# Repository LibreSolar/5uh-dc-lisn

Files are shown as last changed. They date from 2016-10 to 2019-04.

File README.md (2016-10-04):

# 5uH-DC-LISN
5uH DC LISN (-10 dB attenuation)

This LISN enables you to perform basic EMC testing with your DC devices, e.g. power supplies.

The layout (especially the attenuation) is based on Linear Technology DC2130A board design and a [thread in the EEVblog forum](http://www.eevblog.com/forum/projects/5uh-lisn-for-spectrum-analyzer-emcemi-work/msg404662/#msg404662).

Further information on EMC testing can be found in [Würth Application Note ANP005](http://www.we-online.de/web/en/electronic_components/produkte_pb/application_notes/emv_filter_fuer_dc_dc_schaltregler_optimiert.php).

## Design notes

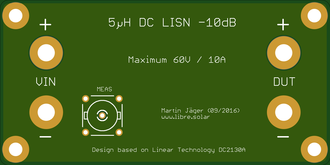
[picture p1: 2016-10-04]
5uH_LISN_bottom.png

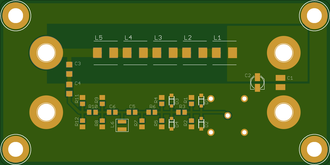
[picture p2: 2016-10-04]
5uH_LISN_top.png

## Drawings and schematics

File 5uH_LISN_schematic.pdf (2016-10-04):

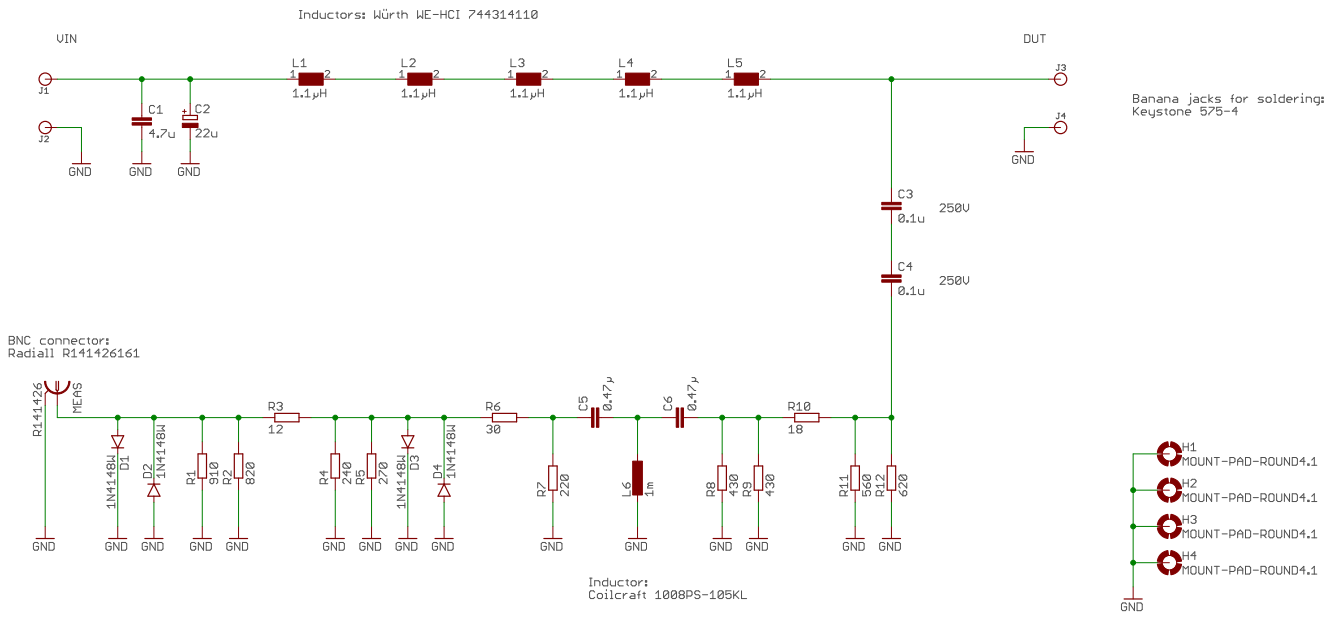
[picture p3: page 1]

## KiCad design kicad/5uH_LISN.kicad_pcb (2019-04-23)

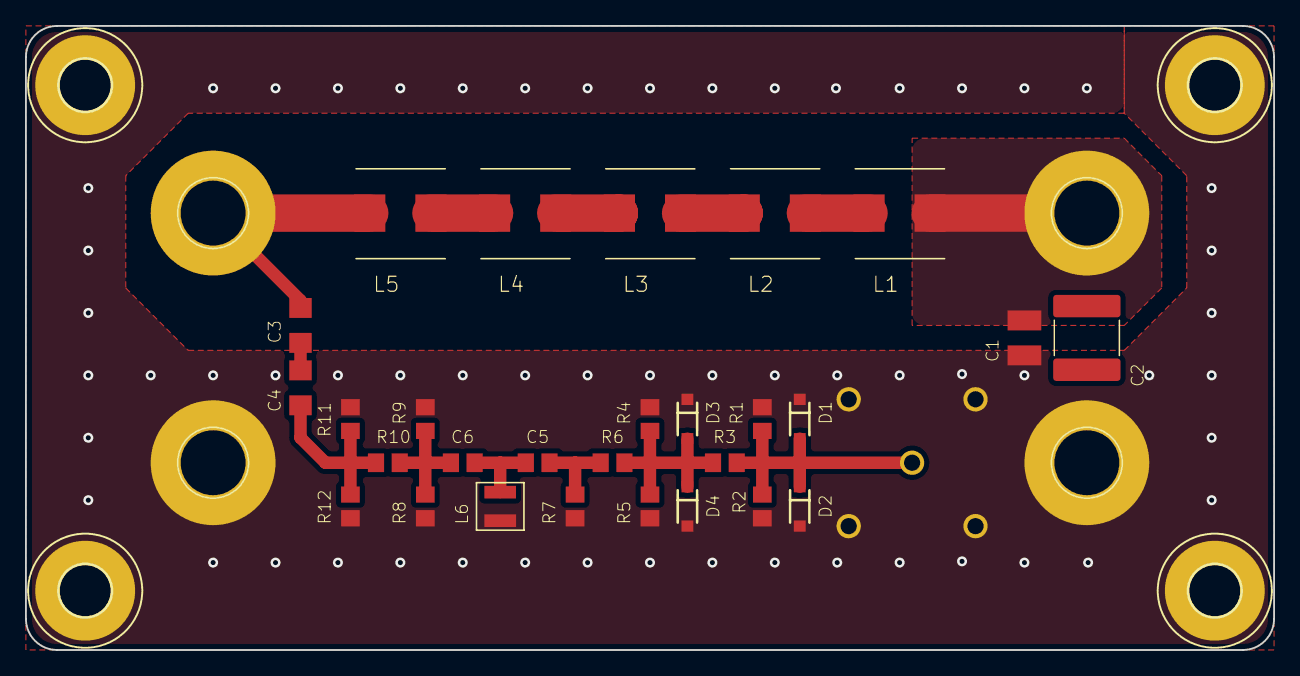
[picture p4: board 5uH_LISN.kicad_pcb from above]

Board: 2 copper layers, 100.0 x 50.0 mm, 37 parts (0 on the bottom side), 14 nets.

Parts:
C1: 4.7u; C1210
C2: 22u; C_2220_5650Metric
C3, C4: 0.1u; C1206
C5, C6: 0.47µ; C0805
D1, D2, D3, D4: 1N4148W; SOD-123
H1, H2, H3, H4: MOUNT-PAD-ROUND4.1; 4,1-PAD
J1, J2, J3, J4: BANANA_CONN
L1, L2, L3, L4, L5: 1.1µH; WE-HCI_7030_7040_7050
L6: 1m; COILCRAFT_1008PS
MEAS1: R141426
R1: 910; R0805
R2: 820; R0805
R3: 12; R0805
R4: 240; R0805
R5: 270; R0805
R6: 30; R0805
R7: 220; R0805
R8, R9: 430; R0805
R10: 18; R0805
R11: 560; R0805
R12: 620; R0805

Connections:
GND: C1.2, D1.C, D2.A, D3.C, D4.A, H1.B4,1, H2.B4,1, H3.B4,1, H4.B4,1, J2.P$1, J4.P$1, L6.P$2, MEAS1.2, MEAS1.3, MEAS1.4, MEAS1.5, R1.1, R2.1, R4.1, R5.1, R7.1, R8.1, R9.1, R11.1, R12.1
unnamed: C1.1, J1.P$1, L1.1
unnamed: C3.1, J3.P$1, L5.2
unnamed: C3.2, C4.1
unnamed: C4.2, R10.2, R11.2, R12.2
unnamed: C5.1, R6.2, R7.2
unnamed: C5.2, C6.1, L6.P$1
unnamed: C6.2, R8.2, R9.2, R10.1
unnamed: D1.A, D2.C, MEAS1.1, R1.2, R2.2, R3.1
unnamed: D3.A, D4.C, R3.2, R4.2, R5.2, R6.1
unnamed: L1.2, L2.1
unnamed: L2.2, L3.1
unnamed: L3.2, L4.1
unnamed: L4.2, L5.1

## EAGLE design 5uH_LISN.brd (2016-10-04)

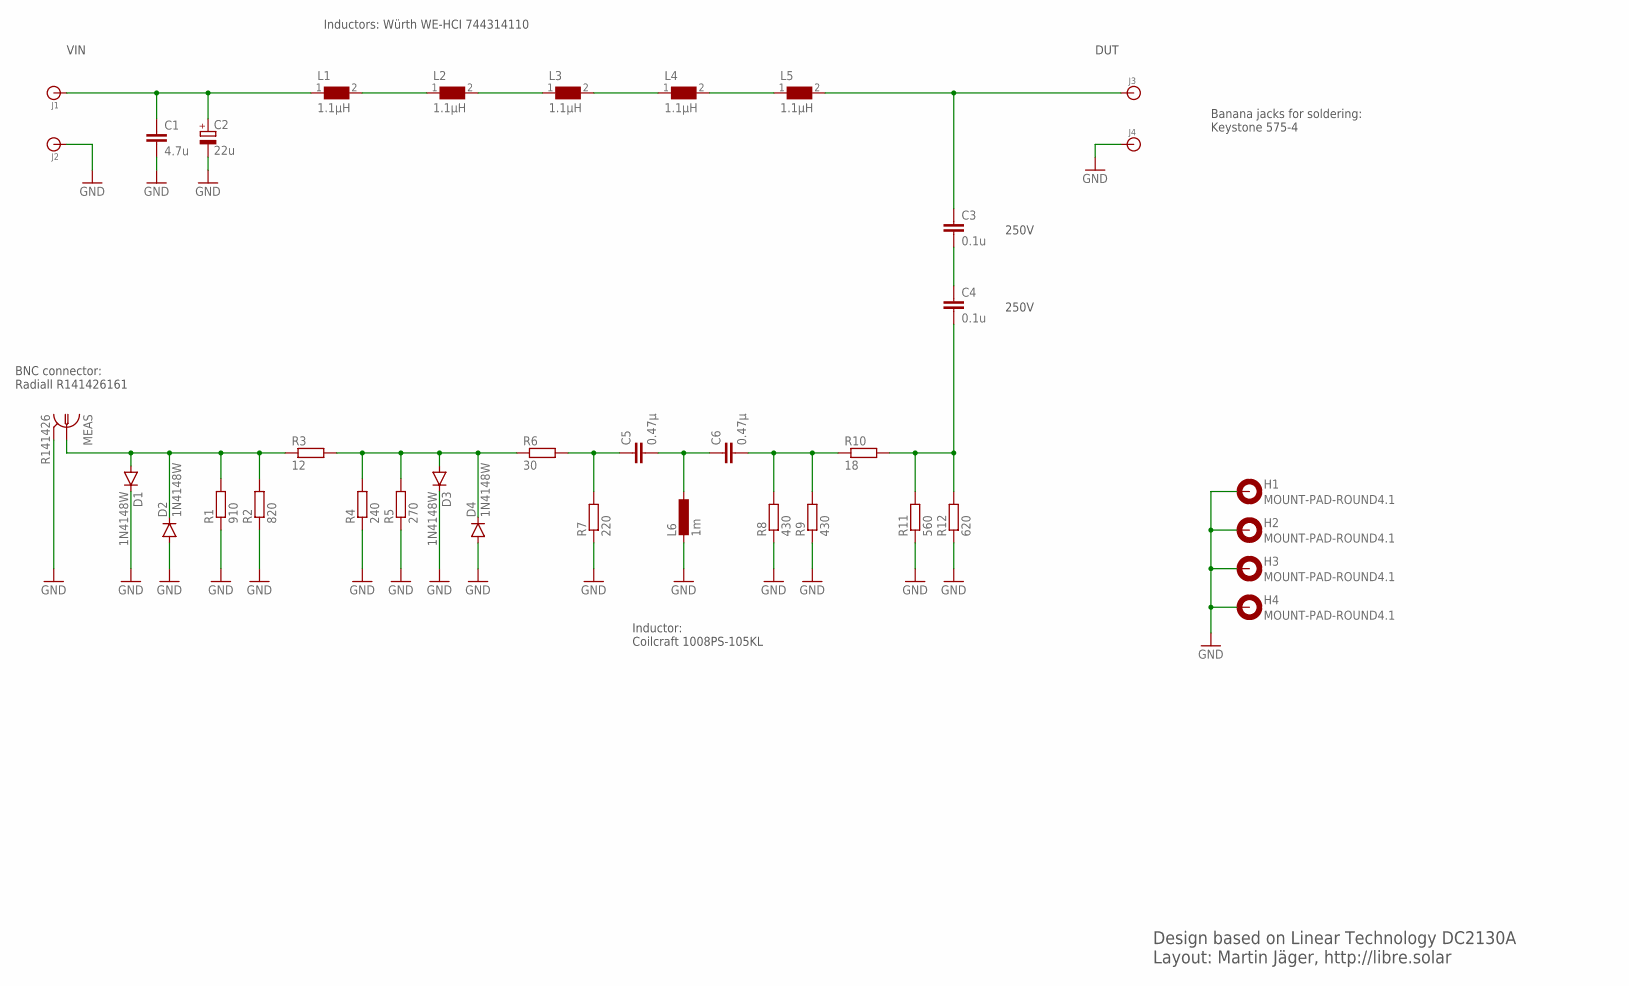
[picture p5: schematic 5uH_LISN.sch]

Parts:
C1: 4.7u; C1210
C2: 22u; PANASONIC_B
C3, C4: 0.1u; C1206
C5, C6: 0.47µ; C0805
D1, D2, D3, D4: 1N4148W; SOD-123; MPN 1N4148W-7-F.
H1, H2, H3, H4: MOUNT-PAD-ROUND4.1; 4,1-PAD
J1, J2, J3, J4: BANANA_CONN
L1, L2, L3, L4, L5: 1.1µH; WE-HCI_7030/7040/7050
L6: 1m; COILCRAFT_1008PS
MEAS: R141426
R1: 910; R0805
R2: 820; R0805
R3: 12; R0805
R4: 240; R0805
R5: 270; R0805
R6: 30; R0805
R7: 220; R0805
R8, R9: 430; R0805
R10: 18; R0805
R11: 560; R0805
R12: 620; R0805

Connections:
GND: C1.2, C2.-, D1.C, D2.A, D3.C, D4.A, H1.B4,1, H2.B4,1, H3.B4,1, H4.B4,1, J2.P$1, J4.P$1, L6.P$2 (2), MEAS.2, MEAS.3 (2), MEAS.4 (2), MEAS.5 (2), R1.1, R2.1, R4.1, R5.1, R7.1, R8.1, R9.1, R11.1, R12.1
unnamed: C1.1, C2.+, J1.P$1, L1.1
unnamed: L1.2, L2.1
unnamed: L2.2, L3.1
unnamed: L3.2, L4.1
unnamed: L4.2, L5.1
unnamed: C3.1, J3.P$1, L5.2
unnamed: C3.2, C4.1
unnamed: D1.A, D2.C, MEAS.1, R1.2, R2.2, R3.1
unnamed: D3.A, D4.C, R3.2, R4.2, R5.2, R6.1
unnamed: C5.1, R6.2, R7.2
unnamed: C5.2, C6.1, L6.P$1 (1)
unnamed: C6.2, R8.2, R9.2, R10.1
unnamed: C4.2, R10.2, R11.2, R12.2

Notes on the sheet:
Inductors: Würth WE-HCI 744314110
Banana jacks for soldering: Keystone 575-4
BNC connector: Radiall R141426161
Inductor: Coilcraft 1008PS-105KL
VIN
DUT
250V
Design based on Linear Technology DC2130A Layout: Martin Jäger, http://libre.solar

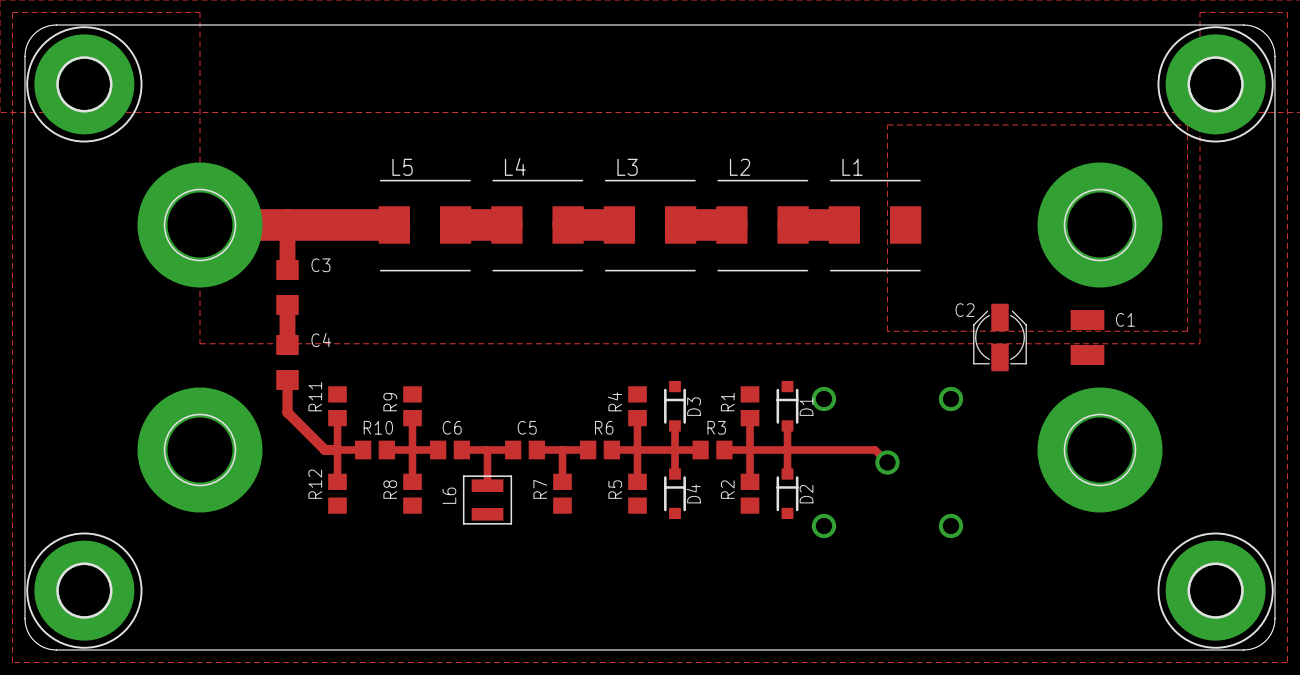
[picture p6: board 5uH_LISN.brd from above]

Board: 2 copper layers, 100.0 x 50.0 mm, 37 parts (1 on the bottom side), 14 nets.

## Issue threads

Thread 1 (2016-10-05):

Wrong package for C2, use size F for 100V rated part

martinjaeger, 2016-10-05:

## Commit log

2016-10-04 Initial commit of schematic and board
    [5uH_LISN.brd, 5uH_LISN.sch]
2019-04-22 Imported to kicad.
    [5uH_LISN.kicad_pcb, 5uH_LISN.sch]
2019-04-22 Cleaned-up kicad layout.
    [5uH_LISN.kicad_pcb]
2019-04-22 Renamed folder containing kicad files.
    [5uH_LISN.kicad_pcb, 5uH_LISN.sch]
2019-04-23 Replaced C2 with C2220 for higher voltage rating. Schematic symbol for C2 no longer polarized. More via stitching.
    [5uH_LISN.kicad_pcb, 5uH_LISN.sch]

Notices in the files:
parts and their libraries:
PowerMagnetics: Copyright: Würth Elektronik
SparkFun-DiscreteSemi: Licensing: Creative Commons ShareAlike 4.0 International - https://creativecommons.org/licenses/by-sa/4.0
